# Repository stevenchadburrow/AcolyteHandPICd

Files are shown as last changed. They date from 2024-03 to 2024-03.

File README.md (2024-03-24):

<b>Acolyte - Hand PIC'd</b>

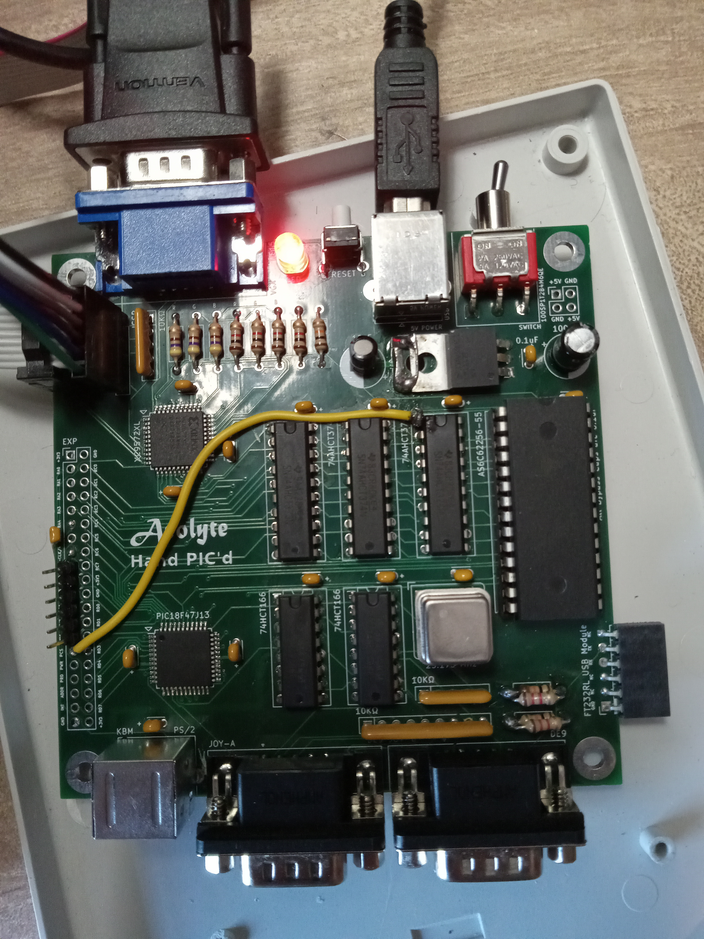
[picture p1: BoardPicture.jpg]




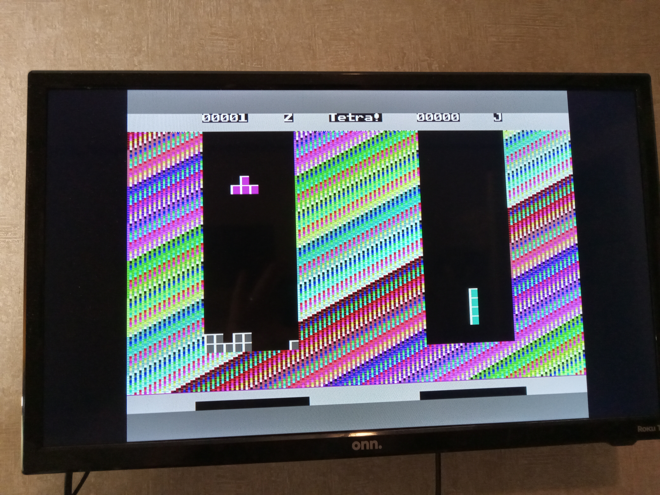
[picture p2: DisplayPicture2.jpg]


This is a PIC-only version of the Acolyte computer.  The main two chips used are the PIC18F47J13 microcontroller and the XC9572XL CPLD.  It contains 32KB of video RAM and has two Sega Genesis controller ports and a PS/2 keyboard port.  The PIC runs off of a 40 MHz oscillator, yet the video is divided down to 5 MHz.  It displays 4 colors per row from 16 total colors, at a resolution of 400 x 256, or 16 colors per row at 200 x 256.

The main reason for leaving the 6502 / 65816 microprocessor is that the PIC allows you to program in C.  Although I have become pretty good at programming in 6502 assembly, I prefer using C because it is 'my native language'.  The goal for this project is to make a fairly cheap, stand-alone computer that will play (multiplayer) video games, like two-player Tetris.  

I am already thinking of additional upgrades though!  I recently added an audio breakout board, so it is now capable of making simple sound effects.  I also added an SDcard and have been able to re-write the flash memory in the PIC with code from the SDcard.

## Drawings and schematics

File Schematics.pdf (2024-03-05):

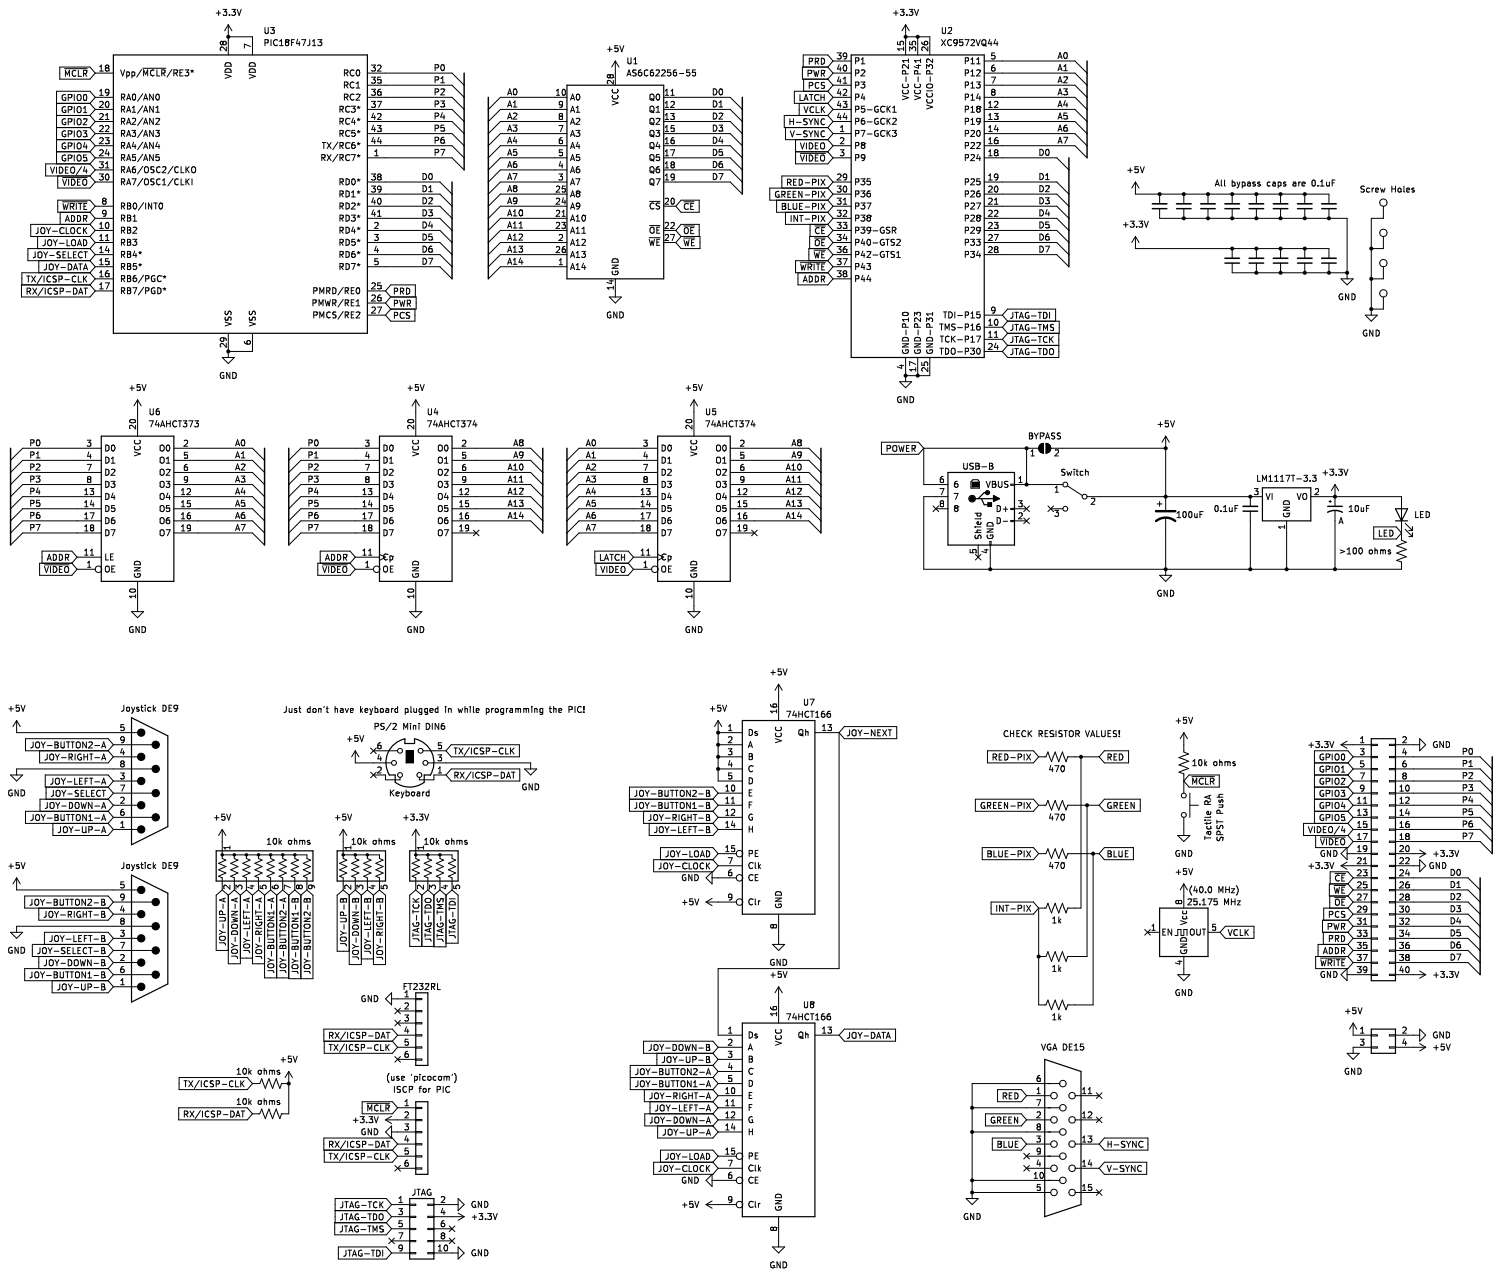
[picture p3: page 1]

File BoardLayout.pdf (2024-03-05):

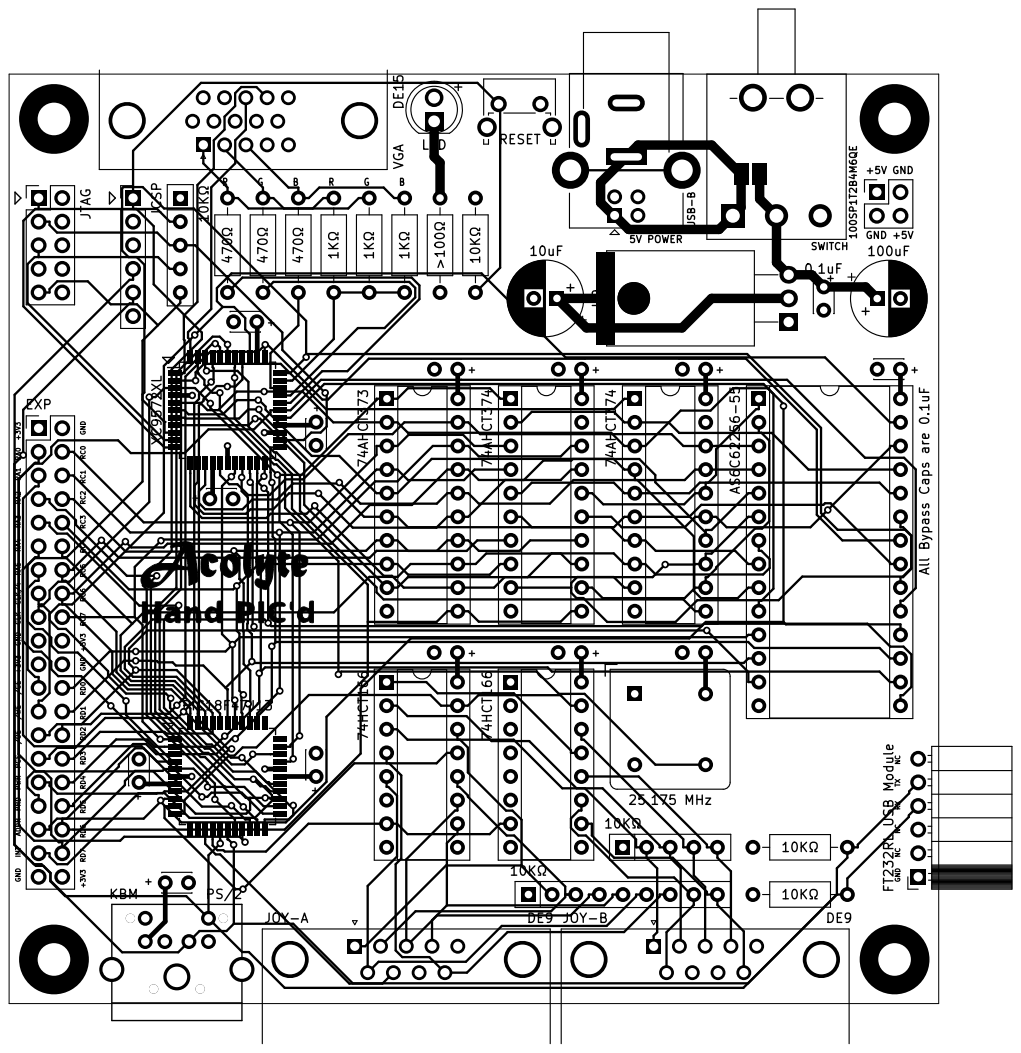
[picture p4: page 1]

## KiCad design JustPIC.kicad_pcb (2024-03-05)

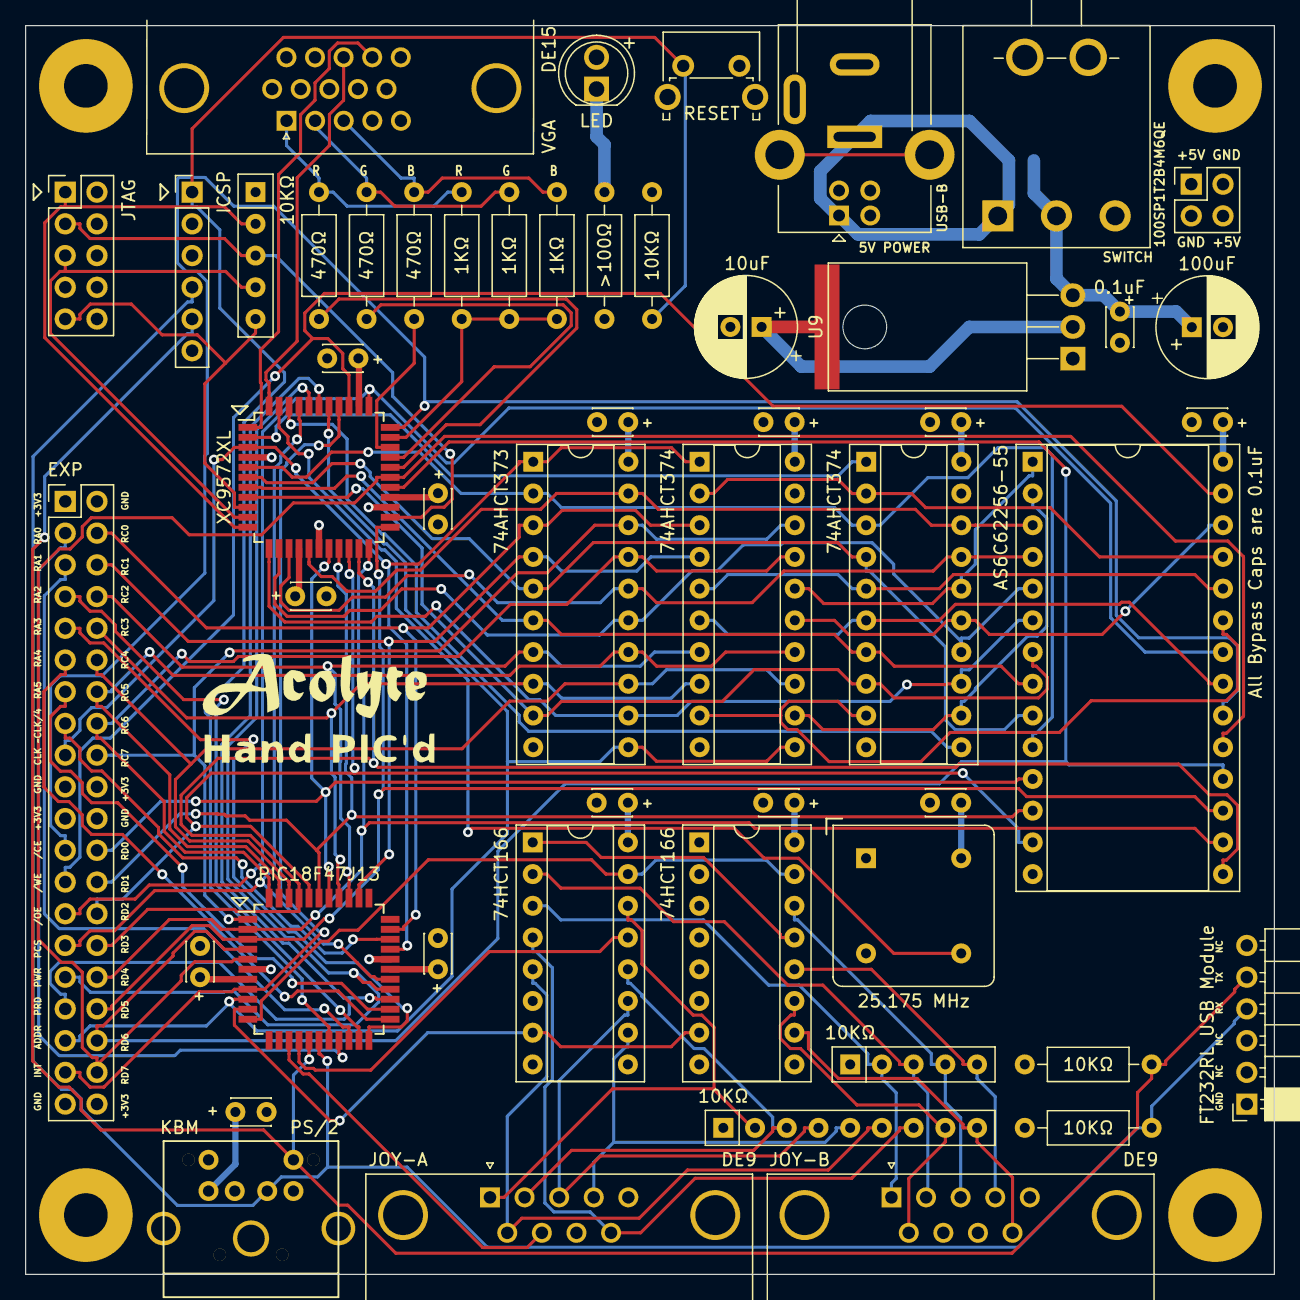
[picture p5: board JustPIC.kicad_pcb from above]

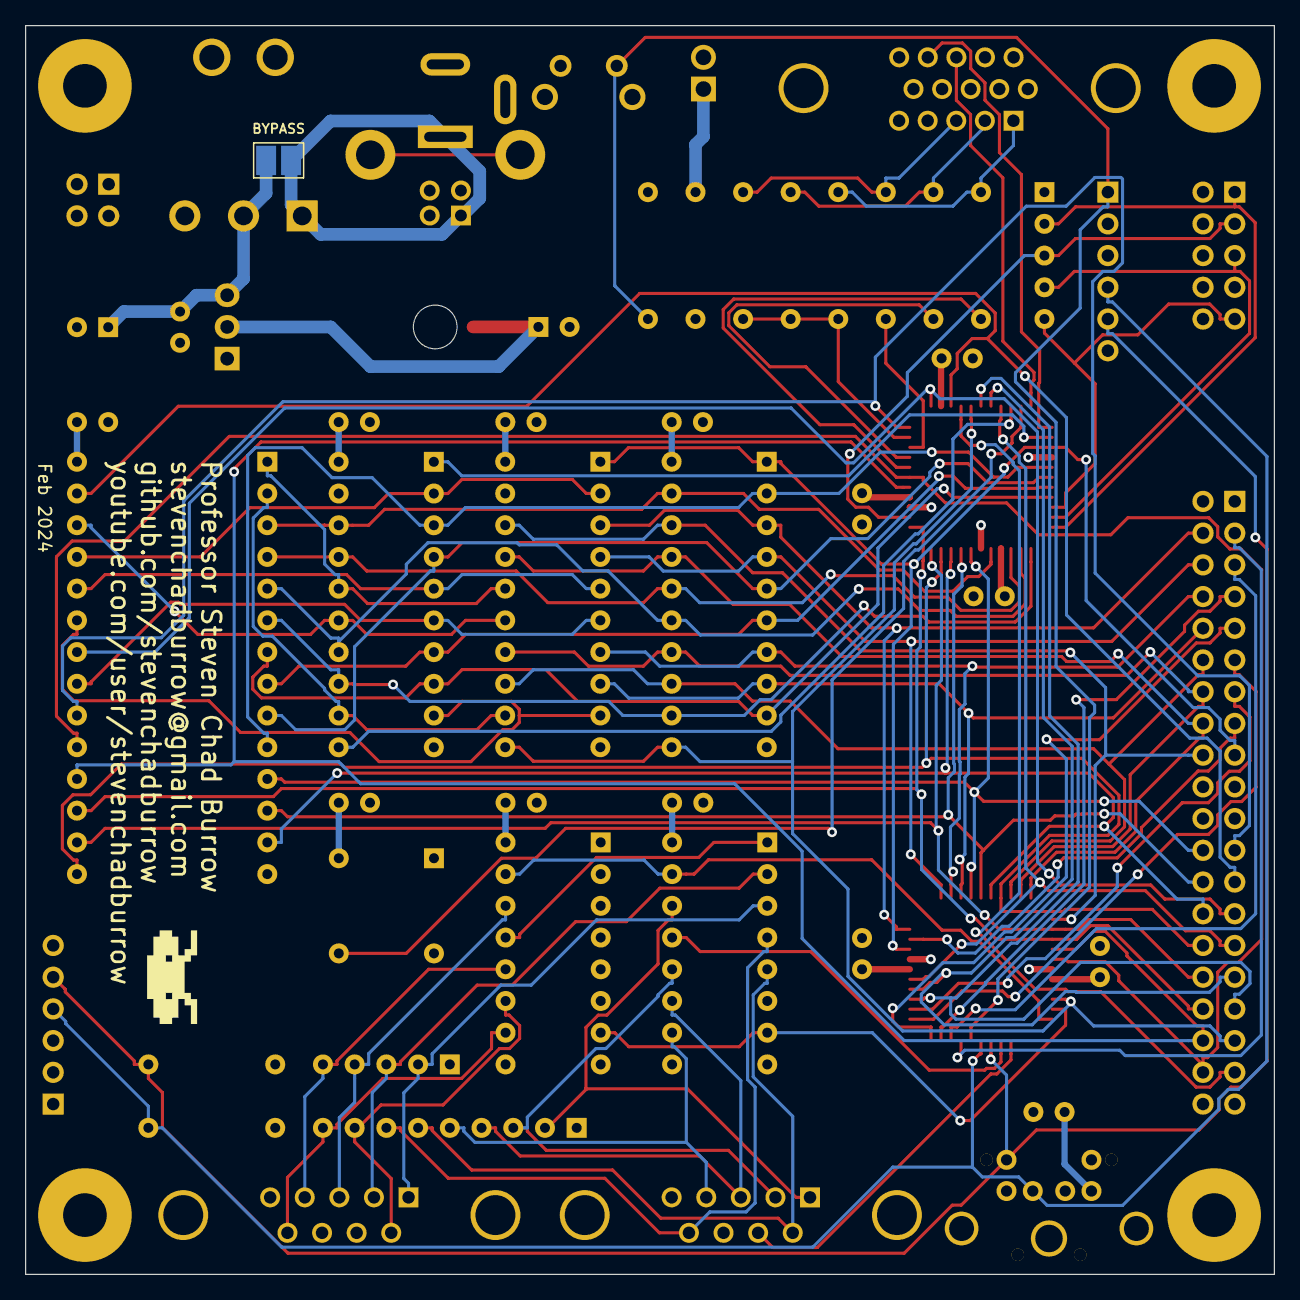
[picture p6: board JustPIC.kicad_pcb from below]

Board: 4 copper layers, 100.0 x 100.0 mm, 60 parts (2 on the bottom side), 88 nets.

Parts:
C1, C2, C3, C8, C9, C10, C12, C15, C16, C20, C22, C23, C24, C26: C_Small; C_Disc_D3.0mm_W2.0mm_P2.50mm
C25: C_Polarized_US; CP_Radial_D8.0mm_P2.50mm
C27: C_Polarized_Small_US; CP_Radial_D8.0mm_P2.50mm
D1: LED; CustomLED
G100: LOGO; AcolyteTitle
G101: LOGO; HandPickedTitle
G102: LOGO; Mystery
J1: DE15_Receptacle_HighDensity; DSUB-15-HD_Female_Horizontal_P2.29x2.54mm_VGA
J2, J3: DE9_Plug; DSUB-9_Male_Horizontal_P2.77x2.84mm_EdgePinOffset7.70mm_Hou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
J4: DualPower_USB_B; DualPowerSupply
J5: Mini-DIN-6; PS2_Din6
J6: Conn_02x20_Odd_Even; PinHeader_2x20_P2.54mm_Vertical
J7: Conn_02x05_Odd_Even; PinHeader_2x05_P2.54mm_Vertical
J8: Conn_01x06; PinHeader_1x06_P2.54mm_Vertical
J9: Conn_02x02_Odd_Even; PinHeader_2x02_P2.54mm_Vertical
J10: Conn_01x06; PinSocket_1x06_P2.54mm_Horizontal
JP1: SolderJumper_2_Open; BIG_SolderJumper-2_P1.3mm_Open_Pad1.0x1.5mm
R1, R2, R3, R4, R5, R6, R7, R8, R9, R10: R_US; R_Axial_DIN0207_L6.3mm_D2.5mm_P10.16mm_Horizontal
RN1, RN4: R_Network04_US; R_Array_SIP5
RN2: R_Network08_US; R_Array_SIP9
SW1: SW_SPDT; SPDT-100SP1T2B4M6QE
SW2: SW_Push; SW_Tactile_SPST_Angled_PTS645Vx83-2LFS
TP1, TP2, TP3, TP4: TestPoint; ScrewHole-4-40
U1: AS6C62256-55; DIP-28_W15.24mm_Socket
U2: XC9572VQ44; TQFP-44_10x10mm_P0.8mm
U3: PIC18F47J13; TQFP-44_10x10mm_P0.8mm
U4, U5: 74AHCT374; DIP-20_W7.62mm_Socket
U6: 74AHCT373; DIP-20_W7.62mm_Socket
U7, U8: 74HCT166; DIP-16_W7.62mm_Socket
U9: LM1117T-3.3; TO-220-3_Horizontal_TabDown-custom
X1: CXO_DIP8; Oscillator_DIP-8

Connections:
+3.3V: C8.2, C12.2, C16.2, C20.2, C24.2, C27.1, D1.2 (A), J6.1, J6.20, J6.21, J6.40, J7.4, J8.2, RN1.1 (common), U2.15 (VCC-P21), U2.26 (VCCIO-P32), U2.35 (VCC-P41), U3.7 (VDD), U3.28 (VDD), U9.2 (VO)
+5V: C1.2, C2.2, C3.2, C9.2, C10.2, C15.2, C22.2, C23.2, C25.1, C26.2, J2.5, J3.5, J5.4, J9.1, J9.4, JP1.2 (B), R8.2, R9.1, R10.1, RN2.1 (common), RN4.1 (common), SW1.2 (B), U1.28 (VCC), U4.20 (VCC), U5.20 (VCC), U6.20 (VCC), U7.1 (Ds), U7.2 (A), U7.3 (B), U7.4 (C), U7.5 (D), U7.9 (Clr), U7.16 (VCC), U8.9 (Clr), U8.16 (VCC), U9.3 (VI), X1.8 (Vcc)
/A0: U1.10 (A0), U2.5 (P11), U5.3 (D0), U6.2 (O0)
/A1: U1.9 (A1), U2.6 (P12), U5.4 (D1), U6.5 (O1)
/A2: U1.8 (A2), U2.7 (P13), U5.7 (D2), U6.6 (O2)
/A3: U1.7 (A3), U2.8 (P14), U5.8 (D3), U6.9 (O3)
/A4: U1.6 (A4), U2.12 (P18), U5.13 (D4), U6.12 (O4)
/A5: U1.5 (A5), U2.13 (P19), U5.14 (D5), U6.15 (O5)
/A6: U1.4 (A6), U2.14 (P20), U5.17 (D6), U6.16 (O6)
/A7: U1.3 (A7), U2.16 (P22), U5.18 (D7), U6.19 (O7)
/A8: U1.25 (A8), U4.2 (O0), U5.2 (O0)
/A9: U1.24 (A9), U4.5 (O1), U5.5 (O1)
/A10: U1.21 (A10), U4.6 (O2), U5.6 (O2)
/A11: U1.23 (A11), U4.9 (O3), U5.9 (O3)
/A12: U1.2 (A12), U4.12 (O4), U5.12 (O4)
/A13: U1.26 (A13), U4.15 (O5), U5.15 (O5)
/A14: U1.1 (A14), U4.16 (O6), U5.16 (O6)
/D0: J6.24, U1.11 (Q0), U2.18 (P24), U3.38 (RD0*)
/D1: J6.26, U1.12 (Q1), U2.19 (P25), U3.39 (RD1*)
/D2: J6.28, U1.13 (Q2), U2.20 (P26), U3.40 (RD2*)
/D3: J6.30, U1.15 (Q3), U2.21 (P27), U3.41 (RD3*)
/D4: J6.32, U1.16 (Q4), U2.22 (P28), U3.2 (RD4*)
/D5: J6.34, U1.17 (Q5), U2.23 (P29), U3.3 (RD5*)
/D6: J6.36, U1.18 (Q6), U2.27 (P33), U3.4 (RD6*)
/D7: J6.38, U1.19 (Q7), U2.28 (P34), U3.5 (RD7*)
/P0: J6.4, U3.32 (RC0), U4.3 (D0), U6.3 (D0)
/P1: J6.6, U3.35 (RC1), U4.4 (D1), U6.4 (D1)
/P2: J6.8, U3.36 (RC2), U4.7 (D2), U6.7 (D2)
/P3: J6.10, U3.37 (RC3*), U4.8 (D3), U6.8 (D3)
/P4: J6.12, U3.42 (RC4*), U4.13 (D4), U6.13 (D4)
/P5: J6.14, U3.43 (RC5*), U4.14 (D5), U6.14 (D5)
/P6: J6.16, U3.44 (TX/RC6*), U4.17 (D6), U6.17 (D6)
/P7: J6.18, U3.1 (RX/RC7*), U4.18 (D7), U6.18 (D7)
ADDR: J6.35, U2.38 (P44), U3.9 (RB1), U4.11 (Cp), U6.11 (LE)
BLUE: J1.3, R4.2, R7.2
BLUE-PIX: R4.1, U2.31 (P37)
GND: C1.1, C2.1, C3.1, C8.1, C9.1, C10.1, C12.1, C15.1, C16.1, C20.1, C22.1, C23.1, C24.1, C25.2, C26.1, C27.2, J1.5, J1.6, J1.7, J1.8, J1.10, J2.8, J3.8, J4.4 (GND), J4.7, J5.3, J6.2, J6.19, J6.22, J6.39, J7.2, J7.10, J8.3, J9.2, J9.3, J10.1, R1.2, SW2.2, TP1.1, TP2.1, TP3.1, TP4.1, U1.14 (GND), U2.4 (GND-P10), U2.17 (GND-P23), U2.25 (GND-P31), U3.6 (VSS), U3.29 (VSS), U4.10 (GND), U5.10 (GND), U6.10 (GND), U7.6 (CE), U7.8 (GND), U8.6 (CE), U8.8 (GND), U9.1 (GND), X1.4 (GND)
GPIO0: J6.3, U3.19 (RA0/AN0)
GPIO1: J6.5, U3.20 (RA1/AN1)
GPIO2: J6.7, U3.21 (RA2/AN2)
GPIO3: J6.9, U3.22 (RA3/AN3)
GPIO4: J6.11, U3.23 (RA4/AN4)
GPIO5: J6.13, U3.24 (RA5/AN5)
GREEN: J1.2, R3.2, R6.2
GREEN-PIX: R3.1, U2.30 (P36)
H-SYNC: J1.13, U2.44 (P6-GCK2)
INT-PIX: R5.1, R6.1, R7.1, U2.32 (P38)
JOY-BUTTON1-A: J2.6, RN2.6 (R5), U8.5 (D)
JOY-BUTTON1-B: J3.6, RN2.8 (R7), U7.11 (F)
JOY-BUTTON2-A: J2.9, RN2.7 (R6), U8.4 (C)
JOY-BUTTON2-B: J3.9, RN2.9 (R8), U7.10 (E)
JOY-CLOCK: U3.10 (RB2), U7.7 (Clk), U8.7 (Clk)
JOY-DATA: U3.15 (RB5*), U8.13 (Qh)
JOY-DOWN-A: J2.2, RN2.3 (R2), U8.12 (G)
JOY-DOWN-B: J3.2, RN4.3 (R2), U8.2 (A)
JOY-LEFT-A: J2.3, RN2.4 (R3), U8.11 (F)
JOY-LEFT-B: J3.3, RN4.4 (R3), U7.14 (H)
JOY-LOAD: U3.11 (RB3), U7.15 (PE), U8.15 (PE)
JOY-NEXT: U7.13 (Qh), U8.1 (Ds)
JOY-RIGHT-A: J2.4, RN2.5 (R4), U8.10 (E)
JOY-RIGHT-B: J3.4, RN4.5 (R4), U7.12 (G)
JOY-SELECT: J2.7, U3.14 (RB4*)
JOY-UP-A: J2.1, RN2.2 (R1), U8.14 (H)
JOY-UP-B: J3.1, RN4.2 (R1), U8.3 (B)
JTAG-TCK: J7.1, RN1.2 (R1), U2.11 (TCK-P17)
JTAG-TDI: J7.9, RN1.5 (R4), U2.9 (TDI-P15)
JTAG-TDO: J7.3, RN1.3 (R2), U2.24 (TDO-P30)
JTAG-TMS: J7.5, RN1.4 (R3), U2.10 (TMS-P16)
LATCH: U2.42 (P4), U5.11 (Cp)
LED: D1.1 (K), R1.1
PCS: J6.29, U2.41 (P3), U3.27 (PMCS/RE2)
POWER: J4.1 (VBUS), J4.6, JP1.1 (A), SW1.1 (A)
PRD: J6.33, U2.39 (P1), U3.25 (PMRD/RE0)
PWR: J6.31, U2.40 (P2), U3.26 (PMWR/RE1)
RED: J1.1, R2.2, R5.2
RED-PIX: R2.1, U2.29 (P35)
RX/ICSP-DAT: J5.1, J8.4, J10.4, R10.2, U3.17 (RB7/PGD*)
TX/ICSP-CLK: J5.5, J8.5, J10.5, R9.2, U3.16 (RB6/PGC*)
V-SYNC: J1.14, U2.1 (P7-GCK3)
VCLK: U2.43 (P5-GCK1), X1.5 (OUT)
VIDEO: U2.2 (P8), U5.1 (OE)
VIDEO/4: J6.15, U3.31 (RA6/OSC2/CLKO)
~CE: J6.23, U1.20 (~CS), U2.33 (P39-GSR)
~MCLR: J8.1, R8.1, SW2.1, U3.18 (Vpp/~MCLR/RE3*)
~OE: J6.27, U1.22 (~OE), U2.34 (P40-GTS2)
~VIDEO: J6.17, U2.3 (P9), U3.30 (RA7/OSC1/CLKI), U4.1 (OE), U6.1 (OE)
~WE: J6.25, U1.27 (~WE), U2.36 (P42-GTS1)
~WRITE: J6.37, U2.37 (P43), U3.8 (RB0/INT0)

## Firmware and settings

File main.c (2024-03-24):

/* Microcontroller MIPs (FCY) */
#define SYS_FREQ        40000000L
#define FCY             SYS_FREQ/4
#define _XTAL_FREQ      SYS_FREQ


// CONFIG1L
#pragma config WDTEN = OFF      // Watchdog Timer (Disabled - Controlled by SWDTEN bit)
#pragma config PLLDIV = 1       // 96MHz PLL Prescaler Selection (PLLSEL=0) (No prescale (4 MHz oscillator input drives PLL directly))
#pragma config CFGPLLEN = OFF//ON    // PLL Enable Configuration Bit (PLL Enabled)
#pragma config STVREN = ON      // Stack Overflow/Underflow Reset (Enabled)
#pragma config XINST = OFF      // Extended Instruction Set (Disabled)

// CONFIG1H
#pragma config CP0 = OFF        // Code Protect (Program memory is not code-protected)

// CONFIG2L
#pragma config OSC = EC
#pragma config SOSCSEL = DIG    // T1OSC/SOSC Power Selection Bits (Digital (SCLKI) mode selected)
#pragma config CLKOEC = ON      // EC Clock Out Enable Bit  (CLKO output enabled on the RA6 pin)
#pragma config FCMEN = OFF      // Fail-Safe Clock Monitor (Disabled)
#pragma config IESO = OFF       // Internal External Oscillator Switch Over Mode (Disabled)

// CONFIG2H
#pragma config WDTPS = 32768    // Watchdog Postscaler (1:32768)

// CONFIG3L
#pragma config DSWDTOSC = INTOSCREF// DSWDT Clock Select (DSWDT uses INTRC)
#pragma config RTCOSC = INTOSCREF// RTCC Clock Select (RTCC uses INTRC)
#pragma config DSBOREN = OFF    // Deep Sleep BOR (Disabled)
#pragma config DSWDTEN = OFF    // Deep Sleep Watchdog Timer (Disabled)
#pragma config DSWDTPS = 2      // Deep Sleep Watchdog Postscaler (1:2 (2.1 ms))

// CONFIG3H
#pragma config IOL1WAY = OFF    // IOLOCK One-Way Set Enable bit (The IOLOCK bit (PPSCON<0>) can be set and cleared as needed)
#pragma config ADCSEL = BIT10   // ADC 10 or 12 Bit Select (10 - Bit ADC Enabled)
#pragma config PLLSEL = PLL4X   // PLL Selection Bit (Selects 4x PLL)
#pragma config MSSP7B_EN = MSK7 // MSSP address masking (7 Bit address masking mode)

// CONFIG4L
#pragma config WPFP = PAGE_127  // Write/Erase Protect Page Start/End Location (Write Protect Program Flash Page 127)
#pragma config WPCFG = OFF      // Write/Erase Protect Configuration Region  (Configuration Words page not erase/write-protected)

// CONFIG4H
#pragma config WPDIS = OFF      // Write Protect Disable bit (WPFP<6:0>/WPEND region ignored)
#pragma config WPEND = PAGE_WPFP// Write/Erase Protect Region Select bit (valid when WPDIS = 0) (Pages WPFP<6:0> through Configuration Words erase/write protected)


/******************************************************************************/
/* Files to Include                                                           */
/******************************************************************************/

#if defined(__XC)
    #include <xc.h>        /* XC8 General Include File */
#elif defined(HI_TECH_C)
    #include <htc.h>       /* HiTech General Include File */
#elif defined(__18CXX)
    #include <p18cxxx.h>   /* C18 General Include File */
#endif

#if defined(__XC) || defined(HI_TECH_C)

#include <stdint.h>        /* For uint8_t definition */
#include <stdbool.h>       /* For true/false definition */

#endif




unsigned int tmr0value = 0x0000;
unsigned int tmr0counter = 0x0000;

void sound(unsigned int value, unsigned int duration)
{
	tmr0value = value;
	tmr0counter = duration;
	
	if (value == 0x0000 || duration == 0x0000) TMR0ON = 0;
	else TMR0ON = 1;
};


unsigned char keyarray[256];
unsigned char keybuffer = 0x00;
unsigned char keycurr = 0x00;
unsigned char keylast = 0x00;
unsigned char keyextended = 0x00;
unsigned char keyrelease = 0x00;
unsigned char keyshift = 0x00;
unsigned char keycapslock = 0x00;
unsigned char keycounter = 0x00;
unsigned char keyreadpos = 0x00;
unsigned char keywritepos = 0x00;


/******************************************************************************/
/* Interrupt Routines                                                         */
/******************************************************************************/

/* High-priority service */

#if defined(__XC) || defined(HI_TECH_C)
void __interrupt(high_priority) high_isr(void)
#elif defined (__18CXX)
#pragma code high_isr=0x08
#pragma interrupt high_isr
void high_isr(void)
#else
#error "Invalid compiler selection for implemented ISR routines"
#endif

{

      /* This code stub shows general interrupt handling.  Note that these
      conditional statements are not handled within 3 seperate if blocks.
      Do not use a seperate if block for each interrupt flag to avoid run
      time errors. */

#if 0
    
      /* TODO Add High Priority interrupt routine code here. */

      /* Determine which flag generated the interrupt */
      if(<Interrupt Flag 1>)
      {
          <Interrupt Flag 1=0>; /* Clear Interrupt Flag 1 */
      }
      else if (<Interrupt Flag 2>)
      {
          <Interrupt Flag 2=0>; /* Clear Interrupt Flag 2 */
      }
      else
      {
          /* Unhandled interrupts */
      }

#endif
	
	if (RBIF == 1)
	{
		RBIF = 0; // clear interrupts for RB

		keycurr = PORTB;

		if ((keylast & 0x40) == 0x40 && (keycurr & 0x40) == 0x00)
		{		
			if (keycounter < 0x09)
			{
				keybuffer = keybuffer >> 1;
				keybuffer = keybuffer | (keycurr & 0x80);
			}

			keycounter++;

			if (keycounter == 0x0B)
			{
				keycounter = 0x00;

				keyarray[keywritepos] = keybuffer;

				keywritepos++;
			}
		}

		keylast = keycurr;
	}
	else if (TMR0IF == 1)
	{
		TMR0IF = 0; // clear interrupts for TMR0
		
		TMR0 = tmr0value; // reset TMR0
		
		if (RA5 == 0) LATA = LATA | 0xF0;
		else LATA = LATA & 0x0F; // toggle RA5
		
		tmr0counter--;
		
		if (tmr0counter == 0x0000) TMR0ON = 0;
	}
	 
	

}

/* Low-priority interrupt routine */
#if defined(__XC) || defined(HI_TECH_C)
void __interrupt(low_priority) low_isr(void)
#elif defined (__18CXX)
#pragma code low_isr=0x18
#pragma interruptlow low_isr
void low_isr(void)
#else
#error "Invalid compiler selection for implemented ISR routines"
#endif
{

      /* This code stub shows general interrupt handling.  Note that these
      conditional statements are not handled within 3 seperate if blocks.
      Do not use a seperate if block for each interrupt flag to avoid run
      time errors. */

#if 0

      /* TODO Add Low Priority interrupt routine code here. */

      /* Determine which flag generated the interrupt */
      if(<Interrupt Flag 1>)
      {
          <Interrupt Flag 1=0>; /* Clear Interrupt Flag 1 */
      }
      else if (<Interrupt Flag 2>)
      {
          <Interrupt Flag 2=0>; /* Clear Interrupt Flag 2 */
      }
      else
      {
          /* Unhandled interrupts */
      }

#endif

}




/******************************************************************************/
/* User Global Variable Declaration                                           */
/******************************************************************************/

/* i.e. uint8_t <variable_name>; */


#include "ExtendedMemory.c"



const unsigned char bitmap[1536] = 
{
	0x00,0x00,0x00,0x00,0x00,0x00,0x00,0x00, // 32
	0x00,0x00,0x00,0x00,0x00,0x00,0x00,0x00,
	0x0F,0x00,0x3F,0xC0,0x3F,0xC0,0x3F,0xC0,
	0x0F,0x00,0x00,0x00,0x0F,0x00,0x00,0x00,
	0x0C,0x30,0x30,0xC0,0x3C,0xF0,0x3C,0xF0,
	0x00,0x00,0x00,0x00,0x00,0x00,0x00,0x00,
	0x3C,0xF0,0xFF,0xFC,0x3C,0xF0,0x3C,0xF0,
	0x3C,0xF0,0xFF,0xFC,0x3C,0xF0,0x00,0x00,
	0x03,0x00,0x3F,0xFC,0xF3,0x00,0x3F,0xF0,
	0x03,0x3C,0xFF,0xF0,0x03,0x00,0x00,0x00,
	0x30,0x0C,0xCC,0x3C,0x30,0xF0,0x03,0xC0,
	0x0F,0x30,0x3C,0xCC,0xF0,0x30,0x00,0x00,
	0x3F,0x00,0xF3,0xC0,0x3F,0x00,0xF3,0xCC,
	0xF0,0xFC,0xF0,0x3C,0x3F,0xF0,0x00,0x00,
	0x0F,0x00,0x0F,0x00,0x03,0x00,0x0C,0x00,
	0x00,0x00,0x00,0x00,0x00,0x00,0x00,0x00,
	0x03,0xF0,0x0F,0x00,0x3C,0x00,0x3C,0x00,
	0x3C,0x00,0x0F,0x00,0x03,0xF0,0x00,0x00,
	0x3F,0x00,0x03,0xC0,0x00,0xF0,0x00,0xF0,
	0x00,0xF0,0x03,0xC0,0x3F,0x00,0x00,0x00,
	0x00,0x00,0x00,0x00,0x3C,0xF0,0x0F,0xC0,
	0x3C,0xF0,0x00,0x00,0x00,0x00,0x00,0x00,
	0x00,0x00,0x00,0x00,0x03,0x00,0x03,0x00,
	0x3F,0xF0,0x03,0x00,0x03,0x00,0x00,0x00,
	0x00,0x00,0x00,0x00,0x00,0x00,0x0F,0x00,
	0x0F,0x00,0x03,0x00,0x0C,0x00,0x00,0x00,
	0x00,0x00,0x00,0x00,0x00,0x00,0x00,0x00,
	0x3F,0xF0,0x00,0x00,0x00,0x00,0x00,0x00,
	0x00,0x00,0x00,0x00,0x00,0x00,0x00,0x00,
	0x00,0x00,0x0F,0x00,0x0F,0x00,0x00,0x00,
	0x00,0x30,0x00,0xF0,0x03,0xC0,0x0F,0x00,
	0x3C,0x00,0xF0,0x00,0xC0,0x00,0x00,0x00,
	0x3F,0xF0,0xF0,0x3C,0xF0,0xFC,0xF3,0x3C,
	0xFC,0x3C,0xF0,0x3C,0x3F,0xF0,0x00,0x00, // 65
	0xFF,0xC0,0x0F,0xC0,0x0F,0xC0,0x0F,0xC0,
	0x0F,0xC0,0x0F,0xC0,0xFF,0xFC,0x00,0x00,
	0x3F,0xF0,0xF0,0x3C,0x00,0xF0,0x0F,0xC0,
	0x3C,0x00,0xF0,0x00,0xFF,0xFC,0x00,0x00,
	0x3F,0xF0,0xF0,0x3C,0x00,0x3C,0x0F,0xF0,
	0x00,0x3C,0xF0,0x3C,0x3F,0xF0,0x00,0x00,
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
};

const unsigned char conversion[256] = 
{
  	0x00,0x16,0x0C,0x0E,0x1E,0x1C,0x1D,0x15,
	0x00,0x18,0x07,0x0F,0x1F,0x09,0x60,0x00,
	0x00,0x00,0x00,0x00,0x00,0x71,0x31,0x00,
	0x00,0x00,0x7A,0x73,0x61,0x77,0x32,0x00,
	0x00,0x63,0x78,0x64,0x65,0x34,0x33,0x00,
	0x00,0x20,0x76,0x66,0x74,0x72,0x35,0x00,
	0x00,0x6E,0x62,0x68,0x67,0x79,0x36,0x00,
	0x00,0x00,0x6D,0x6A,0x75,0x37,0x38,0x00,
	0x00,0x2C,0x6B,0x69,0x6F,0x30,0x39,0x00,
	0x00,0x2E,0x2F,0x6C,0x3B,0x70,0x2D,0x00,
	0x00,0x00,0x27,0x00,0x5B,0x3D,0x00,0x00,
	0x00,0x00,0x0D,0x5D,0x00,0x5C,0x00,0x00,
	0x00,0x00,0x00,0x00,0x00,0x00,0x08,0x00,
	0x00,0x31,0x00,0x34,0x37,0x00,0x00,0x00,
	0x30,0x2E,0x32,0x35,0x36,0x38,0x1B,0x00,
	0x19,0x2B,0x33,0x2D,0x2A,0x39,0x00,0x00,

	0x00,0x16,0x0C,0x0E,0x1E,0x1C,0x1D,0x15,
	0x00,0x18,0x07,0x0F,0x1F,0x09,0x7E,0x00,
	0x00,0x00,0x00,0x00,0x00,0x51,0x21,0x00,
	0x00,0x00,0x5A,0x53,0x41,0x57,0x40,0x00,
	0x00,0x43,0x58,0x44,0x45,0x24,0x23,0x00,
	0x00,0x20,0x56,0x46,0x54,0x52,0x25,0x00,
	0x00,0x4E,0x42,0x48,0x47,0x59,0x5E,0x00,
	0x00,0x00,0x4D,0x4A,0x55,0x26,0x2A,0x00,
	0x00,0x3C,0x4B,0x49,0x4F,0x29,0x28,0x00,
	0x00,0x3E,0x3F,0x4C,0x3A,0x50,0x5F,0x00,
	0x00,0x00,0x22,0x00,0x7B,0x2B,0x00,0x00,
	0x00,0x00,0x0D,0x7D,0x00,0x7C,0x00,0x00,
	0x00,0x00,0x00,0x00,0x00,0x00,0x08,0x00,
	0x00,0x03,0x00,0x13,0x02,0x00,0x00,0x00,
	0x1A,0x7F,0x12,0x35,0x14,0x11,0x1B,0x00,
	0x19,0x2B,0x04,0x2D,0x2A,0x01,0x00,0x00
};

const unsigned char random[224] = 
{
	0, 4, 3, 6, 2, 5, 1,
	4, 1, 3, 5, 2, 0, 6,
	6, 5, 2, 0, 4, 1, 3,
	5, 4, 6, 0, 3, 1, 2,
	
	6, 0, 1, 5, 3, 4, 2,
	2, 4, 0, 5, 1, 6, 3,
	3, 1, 6, 2, 4, 0, 5,
	4, 5, 1, 6, 0, 2, 3,
	
	6, 5, 0, 1, 4, 3, 2,
	3, 5, 2, 6, 1, 0, 4,
	1, 3, 6, 5, 4, 2, 0,
	2, 4, 6, 0, 1, 3, 5,
	
	5, 2, 6, 0, 4, 1, 3,
	5, 0, 2, 4, 6, 1, 3,
	1, 4, 2, 6, 0, 3, 5,
	6, 0, 3, 2, 5, 4, 1,
	
	
	2, 6, 3, 5, 4, 0, 1,
	1, 3, 2, 6, 5, 0, 4,
	6, 4, 0, 3, 5, 2, 1,
	2, 5, 3, 4, 6, 0, 1,
	
	4, 5, 0, 6, 2, 1, 3,
	2, 1, 3, 0, 4, 5, 6,
	2, 0, 5, 4, 6, 1, 3,
	6, 2, 3, 0, 5, 4, 1,
	
	0, 6, 5, 3, 1, 4, 2,
	4, 5, 1, 2, 0, 6, 3,
	4, 1, 6, 3, 0, 2, 5,
	6, 0, 2, 5, 4, 3, 1,
	
	1, 3, 5, 2, 6, 0, 4,
	3, 1, 2, 6, 4, 0, 5,
	4, 2, 0, 1, 6, 3, 5,
	4, 3, 0, 5, 1, 6, 2,
};



// tells if the initialization process worked or not
unsigned char sdcard_ready = 0x00;

// blocks for SDcard
unsigned char sdcard_block_high = 0x00;
unsigned char sdcard_block_mid = 0x00;
unsigned char sdcard_block_low = 0x00;

unsigned char sdcard_block_buffer[512] = {
  0x00, 0x00, 0x00, 0x00, 0x00, 0x00, 0x00, 0x00,
  0x00, 0x00, 0x00, 0x00, 0x00, 0x00, 0x00, 0x00,
  0x00, 0x00, 0x00, 0x00, 0x00, 0x00, 0x00, 0x00,
  0x00, 0x00, 0x00, 0x00, 0x00, 0x00, 0x00, 0x00,
  0x00, 0x00, 0x00, 0x00, 0x00, 0x00, 0x00, 0x00,
  0x00, 0x00, 0x00, 0x00, 0x00, 0x00, 0x00, 0x00,
  0x00, 0x00, 0x00, 0x00, 0x00, 0x00, 0x00, 0x00,
  0x00, 0x00, 0x00, 0x00, 0x00, 0x00, 0x00, 0x00,
  
  0x00, 0x00, 0x00, 0x00, 0x00, 0x00, 0x00, 0x00,
  0x00, 0x00, 0x00, 0x00, 0x00, 0x00, 0x00, 0x00,
  0x00, 0x00, 0x00, 0x00, 0x00, 0x00, 0x00, 0x00,
  0x00, 0x00, 0x00, 0x00, 0x00, 0x00, 0x00, 0x00,
  0x00, 0x00, 0x00, 0x00, 0x00, 0x00, 0x00, 0x00,
  0x00, 0x00, 0x00, 0x00, 0x00, 0x00, 0x00, 0x00,
  0x00, 0x00, 0x00, 0x00, 0x00, 0x00, 0x00, 0x00,
  0x00, 0x00, 0x00, 0x00, 0x00, 0x00, 0x00, 0x00,
  
  0x00, 0x00, 0x00, 0x00, 0x00, 0x00, 0x00, 0x00,
  0x00, 0x00, 0x00, 0x00, 0x00, 0x00, 0x00, 0x00,
  0x00, 0x00, 0x00, 0x00, 0x00, 0x00, 0x00, 0x00,
  0x00, 0x00, 0x00, 0x00, 0x00, 0x00, 0x00, 0x00,
  0x00, 0x00, 0x00, 0x00, 0x00, 0x00, 0x00, 0x00,
  0x00, 0x00, 0x00, 0x00, 0x00, 0x00, 0x00, 0x00,
  0x00, 0x00, 0x00, 0x00, 0x00, 0x00, 0x00, 0x00,
  0x00, 0x00, 0x00, 0x00, 0x00, 0x00, 0x00, 0x00,
  
  0x00, 0x00, 0x00, 0x00, 0x00, 0x00, 0x00, 0x00,
  0x00, 0x00, 0x00, 0x00, 0x00, 0x00, 0x00, 0x00,
  0x00, 0x00, 0x00, 0x00, 0x00, 0x00, 0x00, 0x00,
  0x00, 0x00, 0x00, 0x00, 0x00, 0x00, 0x00, 0x00,
  0x00, 0x00, 0x00, 0x00, 0x00, 0x00, 0x00, 0x00,
  0x00, 0x00, 0x00, 0x00, 0x00, 0x00, 0x00, 0x00,
  0x00, 0x00, 0x00, 0x00, 0x00, 0x00, 0x00, 0x00,
  0x00, 0x00, 0x00, 0x00, 0x00, 0x00, 0x00, 0x00,
  
  0x00, 0x00, 0x00, 0x00, 0x00, 0x00, 0x00, 0x00,
  0x00, 0x00, 0x00, 0x00, 0x00, 0x00, 0x00, 0x00,
  0x00, 0x00, 0x00, 0x00, 0x00, 0x00, 0x00, 0x00,
  0x00, 0x00, 0x00, 0x00, 0x00, 0x00, 0x00, 0x00,
  0x00, 0x00, 0x00, 0x00, 0x00, 0x00, 0x00, 0x00,
  0x00, 0x00, 0x00, 0x00, 0x00, 0x00, 0x00, 0x00,
  0x00, 0x00, 0x00, 0x00, 0x00, 0x00, 0x00, 0x00,
  0x00, 0x00, 0x00, 0x00, 0x00, 0x00, 0x00, 0x00,
  
  0x00, 0x00, 0x00, 0x00, 0x00, 0x00, 0x00, 0x00,
  0x00, 0x00, 0x00, 0x00, 0x00, 0x00, 0x00, 0x00,
  0x00, 0x00, 0x00, 0x00, 0x00, 0x00, 0x00, 0x00,
  0x00, 0x00, 0x00, 0x00, 0x00, 0x00, 0x00, 0x00,
  0x00, 0x00, 0x00, 0x00, 0x00, 0x00, 0x00, 0x00,
  0x00, 0x00, 0x00, 0x00, 0x00, 0x00, 0x00, 0x00,
  0x00, 0x00, 0x00, 0x00, 0x00, 0x00, 0x00, 0x00,
  0x00, 0x00, 0x00, 0x00, 0x00, 0x00, 0x00, 0x00,
  
  0x00, 0x00, 0x00, 0x00, 0x00, 0x00, 0x00, 0x00,
  0x00, 0x00, 0x00, 0x00, 0x00, 0x00, 0x00, 0x00,
  0x00, 0x00, 0x00, 0x00, 0x00, 0x00, 0x00, 0x00,
  0x00, 0x00, 0x00, 0x00, 0x00, 0x00, 0x00, 0x00,
  0x00, 0x00, 0x00, 0x00, 0x00, 0x00, 0x00, 0x00,
  0x00, 0x00, 0x00, 0x00, 0x00, 0x00, 0x00, 0x00,
  0x00, 0x00, 0x00, 0x00, 0x00, 0x00, 0x00, 0x00,
  0x00, 0x00, 0x00, 0x00, 0x00, 0x00, 0x00, 0x00,
  
  0x00, 0x00, 0x00, 0x00, 0x00, 0x00, 0x00, 0x00,
  0x00, 0x00, 0x00, 0x00, 0x00, 0x00, 0x00, 0x00,
  0x00, 0x00, 0x00, 0x00, 0x00, 0x00, 0x00, 0x00,
  0x00, 0x00, 0x00, 0x00, 0x00, 0x00, 0x00, 0x00,
  0x00, 0x00, 0x00, 0x00, 0x00, 0x00, 0x00, 0x00,
  0x00, 0x00, 0x00, 0x00, 0x00, 0x00, 0x00, 0x00,
  0x00, 0x00, 0x00, 0x00, 0x00, 0x00, 0x00, 0x00,
  0x00, 0x00, 0x00, 0x00, 0x00, 0x00, 0x00, 0x00
};


// SDcard commands below
// This was used for the Arduino, but has been modified to work here.
void sdcard_enable(void)
{
	RA2 = 0; // CS is low
}

void sdcard_disable(void)
{
	RA2 = 1; // CS is high
}

void sdcard_longdelay(void)
{
	unsigned int tally = 0x0000;

	while (tally < 0x0400) // arbitrary amount of time to delay, should be around 10ms
	{
		tally = tally + 1;
	}
}

void sdcard_toggle(void)
{
	RA0 = 1; // CLK is high
	RA0 = 0; // CLK is low
}

void sdcard_pump(void)
{
	RA2 = 1; // CS is high, must disable the device
	RA1 = 1; // MOSI is high, AND leave mosi high!!!

	sdcard_longdelay();

	for (unsigned char i=0; i<80; i++)
	{
		sdcard_toggle();
	}
}


void sdcard_sendbyte(unsigned char value)
{
	unsigned char temp_value = value;

	for (unsigned char i=0; i<8; i++)
	{
		if (temp_value >= 0x80)
		{
			RA1 = 1; // MOSI is high
		}
		else
		{
			RA1 = 0; // MOSI is low
		}

		temp_value = temp_value << 1;

		sdcard_toggle();
	}
};


unsigned char sdcard_receivebyte(void)
{
	unsigned char temp_value = 0x00;

	for (unsigned char i=0; i<8; i++)
	{
		temp_value = temp_value << 1;

		if (RB4) // if MISO is high...
		{
			temp_value += 0x01;
		}

		sdcard_toggle();
	}
	
	return temp_value;
};


unsigned char sdcard_waitresult(void)
{
	unsigned char temp_value = 0xFF;

	for (unsigned int i=0; i<2048; i++) // arbitrary wait time
	{
		temp_value = sdcard_receivebyte();

		if (temp_value != 0xFF)
		{
			return temp_value;
		}
	}

	return 0xFF;
}

unsigned char sdcard_initialize(void)
{
	unsigned char temp_value = 0x00;

	RA2 = 1; // CS is high
	RA1 = 1; // MOSI is high
	RA0 = 0; // CLK is low

	sdcard_disable();
	sdcard_pump();
	sdcard_longdelay();
	sdcard_enable();
	sdcard_sendbyte(0x40); // CMD0 = 0x40 + 0x00 (0 in hex)
	sdcard_sendbyte(0x00);
	sdcard_sendbyte(0x00);
	sdcard_sendbyte(0x00);
	sdcard_sendbyte(0x00);
	sdcard_sendbyte(0x95); // CRC for CMD0
	temp_value = sdcard_waitresult(); // command response
	if (temp_value == 0xFF) { return 0; }
	sdcard_disable();
	if (temp_value != 0x01) { return 0; } // expecting 0x01
	sdcard_longdelay();
	sdcard_pump();
	sdcard_enable();
	sdcard_sendbyte(0x48); // CMD8 = 0x40 + 0x08 (8 in hex)
	sdcard_sendbyte(0x00); // CMD8 needs 0x000001AA argument
	sdcard_sendbyte(0x00);
	sdcard_sendbyte(0x01);
	sdcard_sendbyte(0xAA); 
	sdcard_sendbyte(0x87); // CRC for CMD8
	temp_value = sdcard_waitresult(); // command response
	if (temp_value == 0xFF) { return 0; }
	sdcard_disable();
	if (temp_value != 0x01) { return 0; } // expecting 0x01
	sdcard_enable();
	temp_value = sdcard_receivebyte(); // 32-bit return value, ignore
	temp_value = sdcard_receivebyte();
	temp_value = sdcard_receivebyte();
	temp_value = sdcard_receivebyte();
	sdcard_disable();
	do {
		sdcard_pump();
		sdcard_longdelay();
		sdcard_enable();
		sdcard_sendbyte(0x77); // CMD55 = 0x40 + 0x37 (55 in hex)
		sdcard_sendbyte(0x00);
		sdcard_sendbyte(0x00);
		sdcard_sendbyte(0x00);
		sdcard_sendbyte(0x00);
		sdcard_sendbyte(0x01); // CRC (general)
		temp_value = sdcard_waitresult(); // command response
		if (temp_value == 0xFF) { return 0; }
		sdcard_disable();
		if (temp_value != 0x01) { break; } // expecting 0x01, but if not it might already be 'initialized'?
		sdcard_pump();
		sdcard_longdelay();
		sdcard_enable();
		sdcard_sendbyte(0x69); // CMD41 = 0x40 + 0x29 (41 in hex)
		sdcard_sendbyte(0x40); // needed for CMD41?
		sdcard_sendbyte(0x00);
		sdcard_sendbyte(0x00);
		sdcard_sendbyte(0x00);
		sdcard_sendbyte(0x01); // CRC (general)
		temp_value = sdcard_waitresult(); // command response
		if (temp_value == 0xFF) { return 0; }
		sdcard_disable();
		if (temp_value != 0x00 && temp_value != 0x01) { return 0; } // expecting 0x00, if 0x01 try again
		sdcard_longdelay();
	} while (temp_value == 0x01);

	sdcard_ready = 0x01;

	return 1;
}

unsigned char sdcard_readinit(unsigned char high, unsigned char mid, unsigned char low)
{
	unsigned char temp_value = 0x00;

	sdcard_disable();
	sdcard_pump();
	sdcard_longdelay();
	sdcard_enable();
	sdcard_sendbyte(0x51); // CMD17 = 0x40 + 0x11 (17 in hex)
	sdcard_sendbyte(high);
	sdcard_sendbyte(mid);
	sdcard_sendbyte((low&0xFE)); // only blocks of 512 bytes
	sdcard_sendbyte(0x00);
	sdcard_sendbyte(0x01); // CRC (general)
	temp_value = sdcard_waitresult(); // command response
	if (temp_value == 0xFF) { return 0; }
	else if (temp_value != 0x00) { return 0; } // expecting 0x00
	temp_value = sdcard_waitresult(); // data packet starts with 0xFE
	if (temp_value == 0xFF) { return 0; }
	else if (temp_value != 0xFE) { return 0; }
	
	return 1;
}

unsigned char sdcard_readfinal(void)
{
	unsigned char temp_value = 0x00;

	temp_value = sdcard_receivebyte(); // data packet ends with 0x55 then 0xAA
	temp_value = sdcard_receivebyte(); // ignore here
	sdcard_disable();

	return 1;
}

unsigned char sdcard_readblock()
{
	unsigned char temp_value = 0x00;

	if (sdcard_readinit(sdcard_block_high, sdcard_block_mid, sdcard_block_low) == 0) { sdcard_ready = 0x00; }

	for (unsigned int i=0; i<512; i++) // packet of 512 bytes
	{
		// get value from SDcard
		temp_value = sdcard_receivebyte();
		
		sdcard_block_buffer[i] = temp_value;
	}

	if (sdcard_readfinal() == 0) { sdcard_ready = 0x00; }

	if (sdcard_ready == 0x00) { return 0; }
	else { return 1; }
}
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
void main(void)
{
	
  
    /* TODO <INSERT USER APPLICATION CODE HERE> */

	__delay_ms(1000); // delay at beginning until everything is stabilized
	
	// setup initial tri-state and output levels
	PORTA = 0x00;
	LATA = 0x00;
    TRISA = 0x00;
	PORTB = 0x03;
	LATB = 0x00;
	TRISB = 0xF0;
	PORTC = 0x00;
	LATC = 0x00;
	TRISC = 0x00;
	PORTD = 0x00;
	LATD = 0x00;
	TRISD = 0xFF;
	PORTE = 0x00;
	LATE = 0x00;
	TRISE = 0x0F; // 0xFF or 0xF0
	
	// disable interrupts
	INTCON = 0x00;
	INTCON2 = 0x80;
	INTCON3 = 0x00;
	PIE1 = 0x00;
	PIE2 = 0x00;
	PIE3 = 0x00;
	PIE4 = 0x00;
	PIE5 = 0x00;
	
	// enable interrupts for keyboard clock
	IPEN = 1; // enable interrupt priorities
	RBIP = 1; // high priority for RB
	RBIE = 1; // enable interrupt for RB
	GIEH = 1; // enables high priority interrupts
	
	// enable Timer0 and interrupts
	T0CON = 0x0F;
	TMR0IP = 1;
	TMR0IF = 0;
	TMR0IE = 1;
	TMR0 = 0xC000;
	TMR0ON = 1;
	
	sound(0x0000, 0x0000); // turn off sound
	
	
	
	// disable analog for digital I/O
	ANCON0 = 0xFF;
	ANCON1 = 0x1F;
	
	// disable open drain and use TTL on PMP
	ODCON1 = 0x00;
	ODCON2 = 0x00;
	ODCON3 = 0x00;
	PADCFG1 = 0x05; // 0x04 or 0x05
	
	// setup Parallel Master/Slave Port
	PMCONH = 0x00; // disable everything
	PMCONL = 0x0C; // 0x0C or 0x04, low-enable
	PMMODEH = 0x00; 
	PMMODEL = 0x00;
    
	PMEH = 0x00;
	PMEL = 0x00;
	PMADDRH = 0x40; // 0x00 or 0x40?
	PMADDRL = 0x00;
	PMSTATH = 0x00;
	PMSTATL = 0x00;
	
	PMCONH = 0x87; // 0x87, re-enable everything
	PMCONL = 0x84; // 0x80?
	
	
	// clear screen
	for (volatile unsigned char i=0; i<128; i++)
	{
		highaddr((unsigned char)(i));
		
		for (volatile unsigned char j=0; j<100; j++)
		{
			lowaddr((unsigned char)(j));
			writedata(0x00);
		}
		
		for (volatile unsigned char j=100; j<128; j++)
		{
			lowaddr((unsigned char)(j));
			writedata(0xB7); // 0xB7
		}
		
		for (volatile unsigned char j=128; j<228; j++)
		{
			lowaddr((unsigned char)(j));
			writedata(0x00);
		}
		
		for (volatile unsigned char j=228; j<255; j++)
		{
			lowaddr((unsigned char)(j));
			writedata(0xB7); // 0xB7
		}
	}
	
	
	sdcard_splash(0x00);
	
	__delay_ms(5000);
	
	sdcard_splash(0x01);
	
	sdcard_copy();
	
	tmr0value = 0xABCD;
	tmr0counter = 0x01FF; // TEMPORARY!
		
	extendedmemory();
	
	tetra();
	
	scratch();
}
	

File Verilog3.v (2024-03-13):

`timescale 1ns / 1ps
//////////////////////////////////////////////////////////////////////////////////
// Company: 
// Engineer: 
// 
// Create Date:    16:41:04 11/28/2023 
// Design Name: 
// Module Name:    Verilog4 
// Project Name: 
// Target Devices: 
// Tool versions: 
// Description: 
//
// Dependencies: 
//
// Revision: 
// Revision 0.01 - File Created
// Additional Comments: 
//
//////////////////////////////////////////////////////////////////////////////////


/*

Make sure to run fitter like in command line, it allows you to change -optimize to "density" which makes things fit!

cd ~/Xilinx/JustPIC ; ~/Xilinx/14.7/ISE_DS/ISE/bin/lin64/cpldfit -intstyle ise -p xc9572xl-5-VQ44 -ofmt vhdl -optimize density -htmlrpt -loc on -slew fast -init low -inputs 54 -pterms 25 -unused float -power std -terminate keeper Verilog3.ngd ; ~/Xilinx/14.7/ISE_DS/ISE/bin/lin64/hprep6 -s IEEE1149 -n Verilog3 -i Verilog3

cd /usr/share ; sudo xc3sprog -c xpc ~/Xilinx/JustPIC/Verilog3.jed

Use 'xc3sprog' to program the .jed file into the CPLD, but you need to follow some instructions:

Notes for the USB cable
=======================

To use the device as an ordinary user, put the following line in a new
file "libusb-driver.rules" in /etc/udev/rules.d/ and restart udev:
ACTION=="add", SUBSYSTEMS=="usb", ATTRS{idVendor}=="03fd", MODE="666"


If your cable does not have the ID 03fd:0008 in the output of lsusb,
the initial firmware has not been loaded (loading it changes the
product-ID from another value to 8). To load the firmware follow
these steps:

1. Run ./setup_pcusb in this directory, this should set up everything
   correctly:
   - When $XILINX is set correctly:
     $ ./setup_pcusb
   - When $XILINX is not set, and ISE is installed in /opt/Xilinx/13.1:
     $ ./setup_pcusb /opt/Xilinx/13.1/ISE_DS/ISE

Old instructions, use only when the above script did not work:

1. If you have no /etc/udev/rules.d/xusbdfwu.rules file, copy it from
   /path/to/ISE/bin/lin/xusbdfwu.rules to /etc/udev/rules.d/xusbdfwu.rules

2. If you are running a newer version of udev (as in Debian Squeeze and
   Ubuntu 9.10), you need to adapt the rules-file to the new udev-version:
   sed -i -e 's/TEMPNODE/tempnode/' -e 's/SYSFS/ATTRS/g' -e 's/BUS/SUBSYSTEMS/' /etc/udev/rules.d/xusbdfwu.rules

3. Install the package containing /sbin/fxload from your linux distribution.
   It is usually called "fxload"

4. copy the files /path/to/ISE/bin/lin/xusb*.hex to /usr/share/

5. restart udev and re-plug the cable with 'service udev restart'

That should do it???

*/

// This is for the PIC-only system.  
// It should run at 6.28 MHz, giving 16 colors at 320x240 and using 32KB of RAM.
// The PIC will interface using it's Parallel Master Port (technically Parallel Slave Port here)
// much like a 6502 would.  The PIC takes care of it's own addresses.
// This CPLD should have enough room to do vertical OR horizontal scrolling if pre-programmed to do so.


module Verilog3(
	input master_clock, // 25.175 MHz
	inout video, // 6.28 MHz
	output not_video, // inverted clock
	input write, // signals from PIC, want to write when low
	input addr, // signals from PIC, unused?
	output reg hsync, // video sync signals
	output reg vsync,
	output ram_ce, // used to be /CE for RAM, pulled down, now is another clock
	output ram_oe, // /OE for RAM
	output ram_we, // /WE for RAM
	output pic_prd, // parallel read (high enabled)
	output pic_pwr, // parallel write (high enabled)
	output pic_pcs, // use to be parallel chip select (high enabled), now is another clock
	inout [7:0] address,
	inout [7:0] data,
	output latch, // latches upper address (during hsync)
	output reg red,
	output reg green,
	output reg blue,
	output reg intensity
    );

reg half;
reg quarter;
reg eighth;
reg [17:0] video_addr; // video addresses
reg [5:0] color_data;
reg hblank; // blanking values
reg vblank;
reg vscreen;
reg prev;
reg ready_write;
reg ready_read;
reg ready_video;
reg [7:0] preset_colors;

assign video = 1'bz;
assign not_video = master_clock;
assign ram_ce = ~eighth;
assign pic_pcs = eighth;

assign latch = ~hsync;

// these are A0-A7, changed each pixel, inactive during phi2 high or booting,
// these supply A8-A15 during h-sync for external latch
assign address[6:0] = ((~latch && ~eighth) ? video_addr[16:10] :
	((~video) ? video_addr[6:0] :
	7'bzzzzzzz));
assign address[7] = ((~latch && ~eighth) ? video_addr[17] :
	((~eighth) ? prev :
	1'bz));
	
//assign ram_ce = 1'b0;
assign ram_oe = (~eighth ? 1'b0 : (~ready_read ? 1'b0 : 1'b1));
assign ram_we = (~eighth ? 1'b1 : ((~ready_write && quarter) ? 1'b0 : 1'b1));

//assign pic_pcs = (~eighth ? 1'b1 : 1'b0);
assign pic_prd = (~eighth ? 1'b1 : (~ready_write ? 1'b0 : 1'b1));
assign pic_pwr = (~eighth ? 1'b1 : ((~ready_read && quarter) ? 1'b0 : 1'b1)); //((quarter && ~half) || (~quarter && half)) ? 1'b0 : 1'b1)));

assign data[7:0] = 8'bzzzzzzzz;
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
